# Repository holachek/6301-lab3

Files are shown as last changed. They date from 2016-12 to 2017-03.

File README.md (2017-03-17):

# 6301-lab3
Temperature sensor evaluation board for Arduino Nano. Custom PTAT cell and dual-slope ADC design. The PTAT cell features breakaway design of the temperature sense area for remote measurement. Final error after calibration was less than 5%.

Circuit and layout drawn in Altium 17.0.

[BOM for this project as Digikey Cart Share](http://www.digikey.com/short/35444m)

-------

### Revision 1 Errata
Updated Dec 13, 2016

#### Critical/Major
1. R8 should pull up to VCC3V3 for stability, not VCC5V which is not well regulated and prone to noise.
2. U1 pins 2, 4, and 6 (base) should be shorted together. The current design only connects pins 4 and 6, which results in half the expected PTAT current.
3. A 100 ohm resistor should be put across J20 for stability of VREF.

#### Minor
4. Pad size for C5 is too small for most 1uF film capacitors. Suggest to change to 1210 footprint.
5. Jumpers have 0402 footprint, which have pads that do not short well with manual solder rework. Suggest to change to 0805 or 1206 footprint. Alternatively populate with 0402 0 ohm resistors.
6. Add a 4k7 ohm pull up resistor to VCC5V on Arduino pin 12 for one-wire parasitic power.

-------

### 3D Render

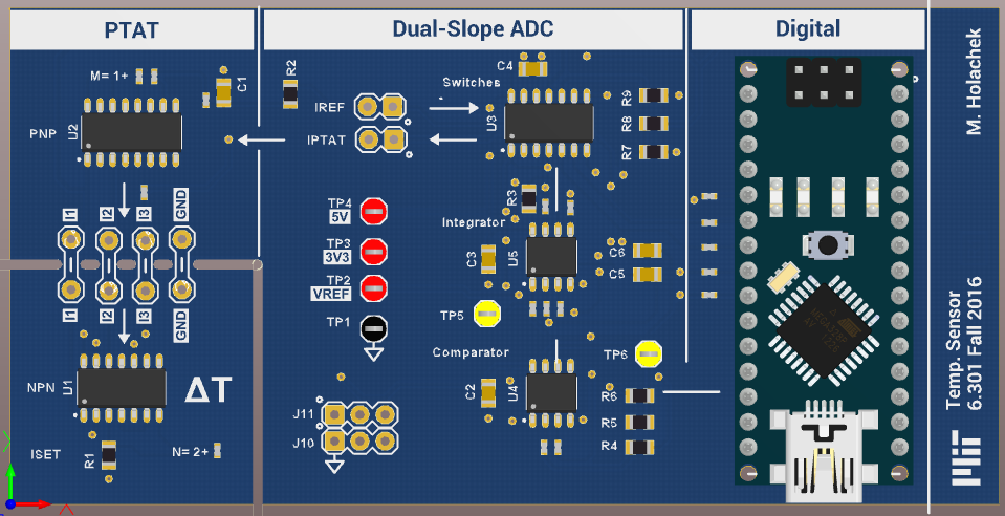
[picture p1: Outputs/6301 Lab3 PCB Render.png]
PCB render


-------

### Conversion Results

Linearity is very good. There is a constant offset error, which can be removed through calibration.

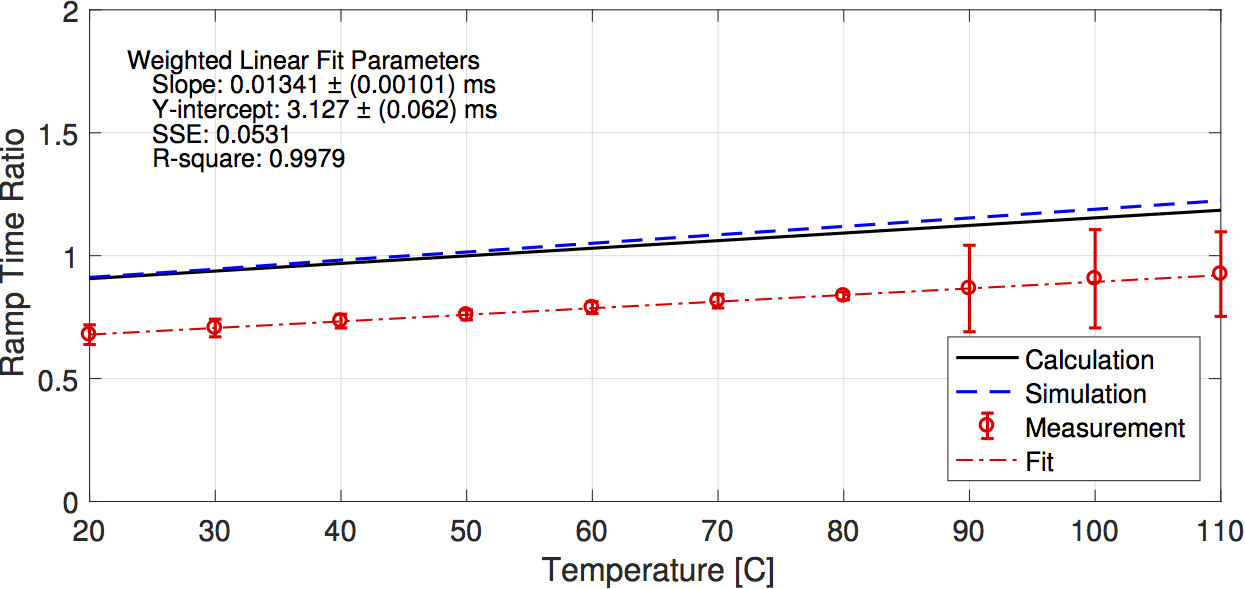
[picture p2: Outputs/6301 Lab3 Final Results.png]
Conversion results. Ramp Time Ratio vs. Temperature.


-------

### Python Plotter Script

The included Python script `plotter.py` allows for a realtime graph of temperature values. It also logs all values to a txt file.

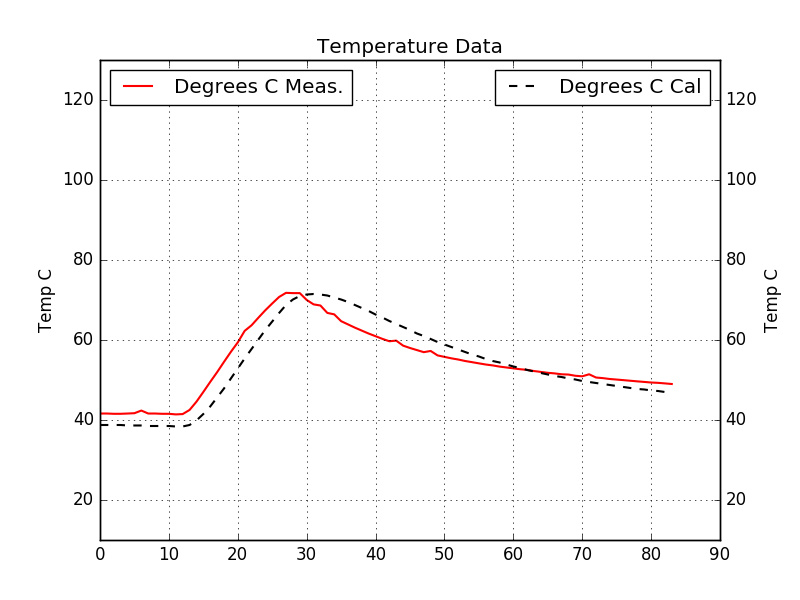
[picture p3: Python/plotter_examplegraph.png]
Screenshot of a graph produced by plotter.py


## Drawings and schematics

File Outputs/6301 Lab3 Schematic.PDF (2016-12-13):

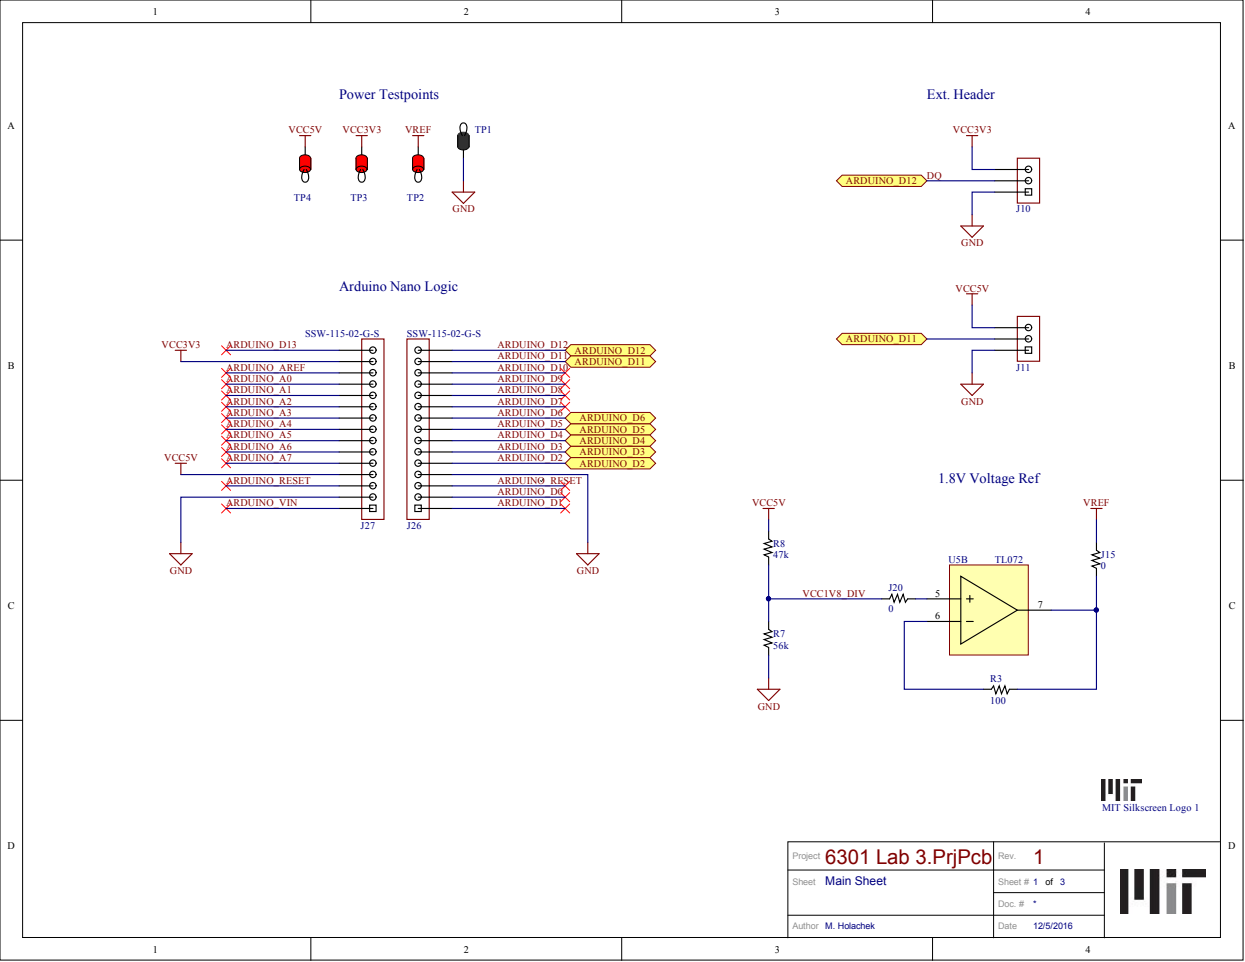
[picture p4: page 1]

6301 Lab 3.PrjPcb Project | Rev. 1

Main Sheet Sheet | Sheet # of

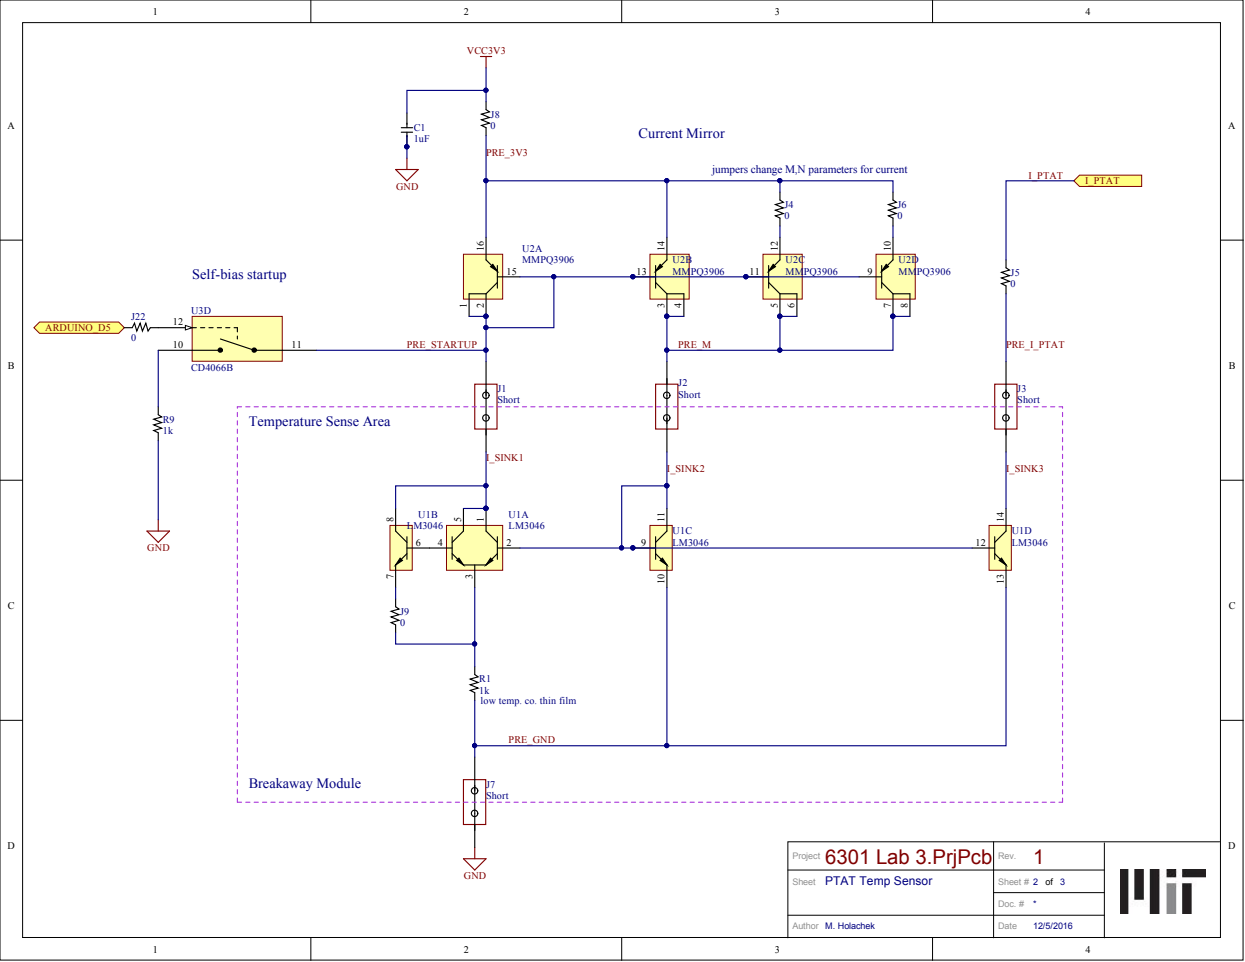
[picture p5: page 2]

jumpers change M,N parameters for current

6301 Lab 3.PrjPcb Project | Rev. 1

PTAT Temp Sensor | Sheet # of

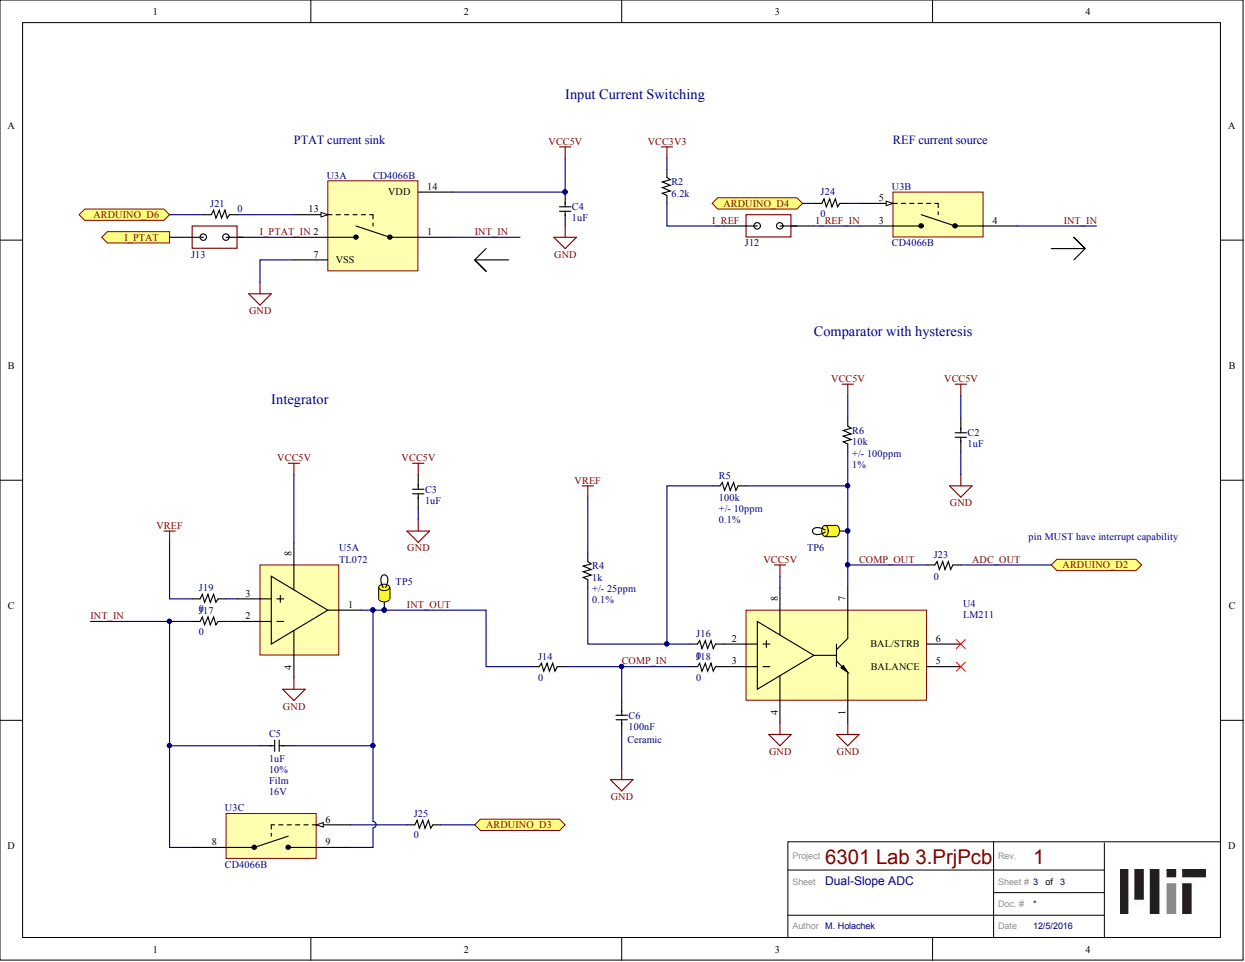
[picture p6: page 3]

pin MUST have interrupt capability

6301 Lab 3.PrjPcb Project | Rev. 1

Dual-Slope ADC | Sheet # of

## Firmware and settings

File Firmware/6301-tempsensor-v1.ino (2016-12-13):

// 6.301 Fall 2016
// Temp Sensor Dual-Slope ADC Firmware
// V1

#include <OneWire.h>
#include <DallasTemperature.h>

// Pinout
const byte sw_ptat = 6;       // IPTAT switch
const byte sw_ref = 4;        // IREF switch
const byte sw_int_short = 3;  // Integrator short/reset switch
const byte sw_startup = 5;    // PTAT startup bias switch
const byte pin_comp_out = 2;  // Comparator output (ensure interrupt capable)
const byte pin_temp_sensor = 12;  // DS18B20 one-wire pin

// One-Wire Temp Sensor Object
OneWire oneWire(pin_temp_sensor);
DallasTemperature sensors(&oneWire);
DeviceAddress tempsensor1 = { 0x28, 0x2E, 0x03, 0x10, 0x05, 0x00, 0x00, 0xF8 };

// Program Variables
int samplecnt = 0; // keep track of number of samples
unsigned long avg = 0; // to average collected data
int firstrun = 1; // to prevent garbage data from being printed when sampling was not run yet

// Manual Calibration Offset
const float calconstant = 25 + 21;

// Timing Values
const uint16_t ramp_up_delta_t_us = 5000;
unsigned long ramp_down_start_time_us = 0;
unsigned long ramp_down_end_time_us = 0;
unsigned long ramp_down_delta_t_us = 0;

// Setup Routine
void setup() {

  // Power Saving
  ADCSRA = ADCSRA & B01111111; // disable ADC
  ACSR = B10000000;            // disable analog comparator
  DIDR0 = DIDR0 | B00111111;   // disable input buffers on analog pins

  // Configure IO pins
  pinMode(sw_ptat, OUTPUT);
  pinMode(sw_ref, OUTPUT);
  pinMode(sw_int_short, OUTPUT);
  pinMode(sw_startup, OUTPUT);
  pinMode(pin_comp_out, INPUT);

  // Start serial terminal
  Serial.begin(115200);

  // Start One-Wire bus
  sensors.begin();
  sensors.setResolution(tempsensor1, 11);  // 11 bits, 0.125C resolution, 375ms conv time
   
  // Configure interrupt
  attachInterrupt( digitalPinToInterrupt( pin_comp_out ), isr_comp, RISING );

  // Default pin values
  digitalWrite( sw_ptat, LOW );
  digitalWrite( sw_ref, LOW );
  digitalWrite( sw_int_short, LOW );

  // Startup PTAT
  digitalWrite( sw_startup, HIGH );
  delay(30);
  digitalWrite( sw_startup, LOW );

  // Ramp the integrator all the way up so that the ADC can start
  // even if the integrator initial condition is negative
  digitalWrite( sw_ptat, HIGH );
  digitalWrite( sw_ref, LOW );
  
  delay(200);

  // Start the first ramp-down
  digitalWrite( sw_ptat, LOW );
  digitalWrite( sw_ref, HIGH );

}



void loop() {
  cli();  // Disable interrupts
  unsigned long ramp_down_delta_t_us_sample = ramp_down_delta_t_us;
  unsigned long ramp_down_start_time_us_sample = ramp_down_start_time_us;
  unsigned long ramp_down_end_time_us_sample = ramp_down_end_time_us;
  
  sei();  // Enable interrupts
  
  sensors.requestTemperatures();
  
  if (samplecnt == 0){
    // reset things, as temp sampling has stopped or cycle has been interrupted
    digitalWrite( sw_int_short, HIGH );
    digitalWrite( sw_startup, HIGH );
    delay(50);
    digitalWrite(sw_startup, LOW );
    digitalWrite(sw_int_short, LOW );
    Serial.println("Reset asserted by cycle watchdog");
    firstrun = 1;
    
  } else if(firstrun == 1) {

    firstrun = 0;
    avg = 0;
    samplecnt = 0;
    
  } else {

    cli();
    avg = avg / (samplecnt);
    unsigned long avg_sample = avg;
    avg = 0;
    samplecnt = 0;
    sei();

    float local_temp = calculate_temperature_calibrated(avg_sample);
    float cal_temp = sensors.getTempCByIndex(0);
    float error = local_temp - cal_temp;

    Serial.print(ramp_down_delta_t_us_sample);
    Serial.print(",");
    Serial.print(local_temp);
    Serial.print(",");
    Serial.println(cal_temp);

  }


  
  delay(100);
}

// sample cycle finished
void isr_comp() {
  cli();  // Disable interrupts

  // Stop the integrator ramp-down
  digitalWrite( sw_ref, LOW );

  // Figure out the ramp-down time
  ramp_down_end_time_us = micros();
  ramp_down_delta_t_us = ramp_down_end_time_us - ramp_down_start_time_us;

  samplecnt += 1;
  avg = (avg + ramp_down_delta_t_us);

  // State 3: Reset
  digitalWrite( sw_int_short, HIGH );
  delayMicroseconds(10);
  digitalWrite( sw_int_short, LOW );
  
  // Stage 1: Ramp-up

  // Start the integrator ramp-up
  digitalWrite(sw_ptat, HIGH);

  // Integrate the known current for a known amount of time
  delayMicroseconds(ramp_up_delta_t_us);

  // Stop the integrator ramp-up
  digitalWrite(sw_ptat, LOW);

  // State 2: Ramp-down

  // Start the integrator ramp-down
  digitalWrite(sw_ref, HIGH);
  ramp_down_start_time_us = micros();

  EIFR = 0x01; // Clear any pending interrupts on INT0

  sei(); // Enable interrupts
}

// Uses the calibration curve to calculate the temperature
float calculate_temperature( unsigned long ramp_down_delta_t_us ) {
  return (ramp_down_delta_t_us*171e-6*1.6e-19*1e3)/(ramp_up_delta_t_us*1.38e-23*3*1.792) - 273.15;
}

float calculate_temperature_calibrated( unsigned long ramp_down_delta_t_us ) {
  return calculate_temperature( ramp_down_delta_t_us ) + calconstant;
}

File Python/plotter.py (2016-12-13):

# Plot temperature output from sensor serial
# Code derived from http://www.toptechboy.com/tutorial/python-with-arduino-lesson-11-plotting-and-graphing-live-data-from-arduino-with-matplotlib/

import serial
import numpy
import matplotlib.pyplot as plt
from drawnow import *
import datetime

tempC_meas = []
tempC_cal = []
ramp_times = []

arduinoData = serial.Serial('/dev/tty.usbserial-A6041C4L', 115200) #Creating our serial object named arduinoData
plt.ion() # interactive mode
cnt=0

today = datetime.datetime.today()
timeformat = "%b%d_%H-%M-%S"
filename = "datalog_" + today.strftime(timeformat) + ".txt"

with open(filename, "w") as myfile:
    myfile.write("\n\nRUN at " + str(datetime.datetime.now()) + "\n")
    myfile.write("<t_down, meas_tempC, cal_tempC>\n")

def makeFig(): #Create a function that makes our desired plot
    plt.ylim(10,120)                                 #Set y min and max values
    plt.title('Temperature Data')      #Plot the title
    plt.grid(True)                                  #Turn the grid on
    plt.ylabel('Temp C')                            #Set ylabels
    plt.plot(tempC_meas, 'r-', linewidth=1.5, label='Degrees C Meas.')       #plot the temperature
    plt.legend(loc='upper left')                    #plot the legend
    plt2=plt.twinx()                                #Create a second y axis
    plt.ylim(10,120)                           #Set limits of second y axis- adjust to readings you are getting
    plt2.plot(tempC_cal, 'k--', linewidth=1.5, label='Degrees C Cal') #plot tempC_cal data
    plt2.set_ylabel('Temp C')                    #label second y axis
    plt2.ticklabel_format(useOffset=False)           #Force matplotlib to NOT autoscale y axis
    plt2.legend(loc='upper right')                  #plot the legend
 
while True: # While loop that loops forever
    while (arduinoData.inWaiting()==0): #Wait here until there is data
        pass #do nothing
    arduinoString = arduinoData.readline() #read the line of text from the serial port
    try:
        dataArray = arduinoString.split(',')   #Split it into an array called dataArray
        ramp_time = float( dataArray[0])
        tempC_meas_point = float( dataArray[1])            #Convert first element to floating number and put in temp
        tempC_cal_point =    float( dataArray[2])            #Convert second element to floating number and put in P
        tempC_meas.append(tempC_meas_point)                     #Build our tempC_meas array by appending temp readings
        tempC_cal.append(tempC_cal_point)                     #Building our tempC_cal array by appending P readings
        ramp_times.append(ramp_time)
        cnt=cnt+1
    except:
        pass
    with open(filename, "a") as myfile:
        myfile.write(arduinoString)
    drawnow(makeFig)                       #Call drawnow to update our live graph
    plt.pause(.000001)                     #Pause Briefly. Important to keep drawnow from crashing
    if(cnt>150):                            #If you have 50 or more points, delete the first one from the array
        tempC_meas.pop(0)                       #This allows us to just see the last 50 data points
        tempC_cal.pop(0)

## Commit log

2016-12-06 Commit all files.
    [6301 Lab 3.PcbLib, 6301 Lab 3.PrjPcb, 6301 Lab 3.SchLib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]
2016-12-06 Added PCB render.
2016-12-06 Updated PCB render.
2016-12-06 Updated schematic formatting.
2016-12-13 Added firmware and updated schematic.
